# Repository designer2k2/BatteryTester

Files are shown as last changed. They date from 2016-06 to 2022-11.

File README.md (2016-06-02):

# BatteryTester
Arduino Shield to test 1-3S LiPo´s

There are KiCad Files (for 4.0.2) and the Arduino Programm here!

This shield has large resistors switched by mosfets, that gives the possibilty to change the load to the connected cells.

Image of Prototype

it measures the capacity and Internal resistance, you can plot the data in graphs if you like:

Image of discharge curve

It is based on my prototype from here: http://www.designer2k2.at/mods/arduino/70-battery-tester

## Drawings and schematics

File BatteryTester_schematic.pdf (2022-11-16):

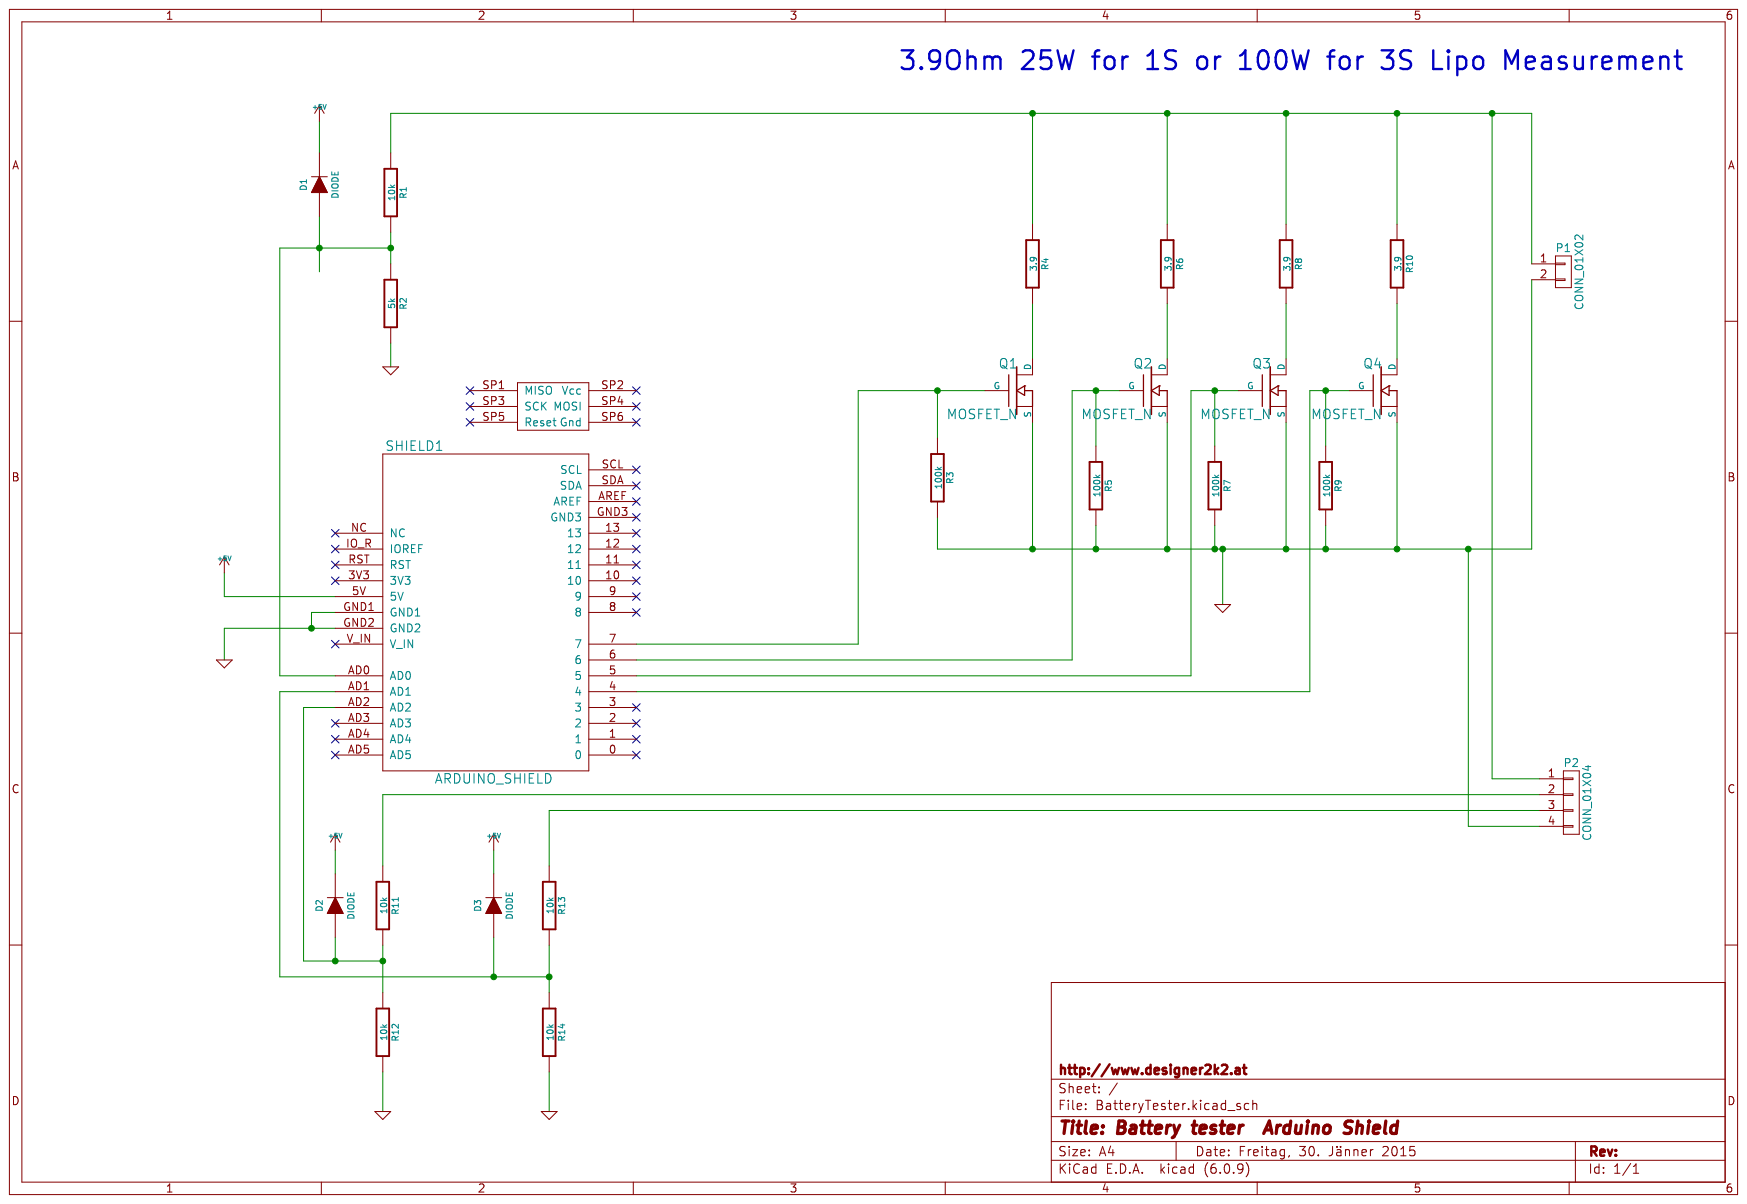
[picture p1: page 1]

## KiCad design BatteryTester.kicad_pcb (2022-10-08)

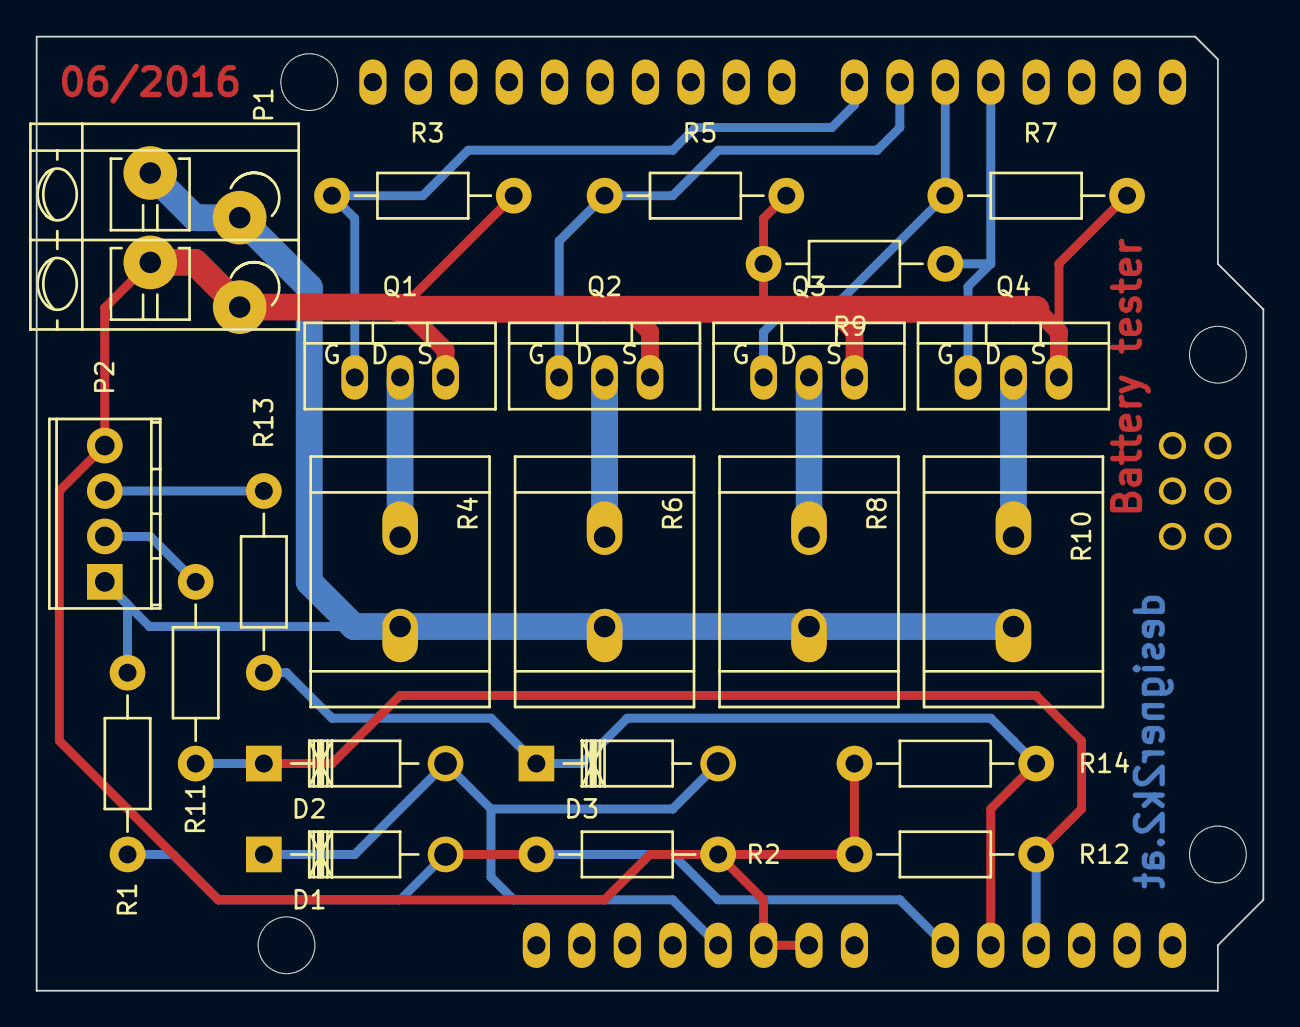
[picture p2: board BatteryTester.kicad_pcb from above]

Board: 2 copper layers, 68.6 x 53.3 mm, 24 parts (0 on the bottom side), 16 nets.

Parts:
D1, D2, D3: DIODE; Diode_DO-41_SOD81_Horizontal_RM10
P1: CONN_01X02; TerminalBlock_WAGO-804_RM5mm_2pol
P2: CONN_01X04; TerminalBlock_Pheonix_MPT-2.54mm_4pol
Q1, Q2, Q3, Q4: MOSFET_N; TO-220_FET-GDS_Vertical
R1, R11, R12, R13, R14: 10k; Resistor_Horizontal_RM10mm
R2: 5k; Resistor_Horizontal_RM10mm
R3, R5, R7, R9: 100k; Resistor_Horizontal_RM10mm
R4, R6, R8, R10: 3.9; Resistor_Cement_Vertical_LargePads_KOA-BGR-5N-7N
SHIELD1: ARDUINO_SHIELD

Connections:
+5V: D1.2, D2.2, D3.2, SHIELD1.5V
GND: P1.2, P2.4, Q1.S, Q2.S, Q3.S, Q4.S, R2.2, R3.2, R5.2, R7.2, R9.2, R12.2, R14.2, SHIELD1.GND1, SHIELD1.GND2
unnamed: D1.1, R1.2, R2.1, SHIELD1.AD0
unnamed: D2.1, R11.2, R12.1, SHIELD1.AD2
unnamed: D3.1, R13.2, R14.1, SHIELD1.AD1
unnamed: P1.1, P2.1, R1.1, R4.1, R6.1, R8.1, R10.1
unnamed: P2.2, R11.1
unnamed: P2.3, R13.1
unnamed: Q1.D, R4.2
unnamed: Q1.G, R3.1, SHIELD1.7
unnamed: Q2.D, R6.2
unnamed: Q2.G, R5.1, SHIELD1.6
unnamed: Q3.D, R8.2
unnamed: Q3.G, R7.1, SHIELD1.5
unnamed: Q4.D, R10.2
unnamed: Q4.G, R9.1, SHIELD1.4

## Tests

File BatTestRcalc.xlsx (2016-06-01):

Zellen: | 1
V: | 3.7
 |  | Ohm | A | W | AT | WT
 |  | 3.9 | 0.95 | 3.51 | 4.74 | 17.55
 |  | 3.9 | 0.95 | 3.51
 |  | 3.9 | 0.95 | 3.51
 |  | 1.95 | 1.90 | 7.02

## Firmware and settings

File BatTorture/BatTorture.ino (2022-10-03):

//Battery Tester by Stephan Martin
//http://www.designer2k2.at
// 03.07.2012 Initial Version
// 31.08.2012 Start to add Ri Measurement (1sec free, 1sec 1A, 1sec free, 1sec 2A, 1sec free, 1sec 3A, 1sec free) NO Protection
// 09.09.2014 Extend Ri Measurement (take last sample and calc Ri)
// 17.09.2014 Start to add Capacity measurement, per chanel we have a 3.9Ohms R
// 10.10.2014 Capacity works, now add Wh, and make Ri automatically, maybe use timer to get 100ms intervall?

#include<stdlib.h> //for dtostrf(FLOAT,WIDTH,PRECSISION,BUFFER);
static char dtostrfbuffer1[20];

const int analogInPin = 0;  // Analog input pin that the Battery is attached to

int sensorValue = 0;        // value read from the Battery
float SensorVoltage = 0.0;
int ChargeInput = 0;
unsigned long time;
unsigned long Start = 0;
int Mosfets = 0;
boolean RunIt = false;
boolean ChargeIt = false;

float FreeVoltage, Volt1A, Volt2A, Volt3A, Ri1A, Ri2A, Ri3A;

float fCapacity = 0.0;
unsigned long lasttime = 0;

void setup() {

  //Define Mosfet Pins as Outputs
  pinMode(5, OUTPUT);
  pinMode(6, OUTPUT);
  pinMode(7, OUTPUT);

  //And the Charge IC Pins:
  pinMode(4, OUTPUT); //Current select (High 500ma, Low 100ma)
  pinMode(2, OUTPUT); //Enable (High On, Low Off)

  //and give them a clear off:
  digitalWrite(5, LOW);
  digitalWrite(6, LOW);
  digitalWrite(7, LOW);
  digitalWrite(4, LOW);
  digitalWrite(2, LOW);

  // initialize serial communications at 9600 bps:
  Serial.begin(57600);

  pinMode(13, OUTPUT);

  // Ask for the Mosfets
  IntroTextSend();

}

void loop() {



  // check if data has been sent from the computer:
  if (Serial.available()) {
    Mosfets = Serial.parseInt();
    //Serial.print(Mosfets);

    switch (Mosfets) {
      case 1:
        //1 Mosfet (Center)
        Serial.println("Activate the center, 1A!");
        digitalWrite(2, LOW);
        digitalWrite(4, LOW);
        ChargeIt = false;
        digitalWrite(5, LOW);
        digitalWrite(6, HIGH);
        digitalWrite(7, LOW);
        RunIt = true;
        break;
      case 2:
        //2 Mosfet (edges)
        Serial.println("Activate the edges, 2A!");
        digitalWrite(2, LOW);
        digitalWrite(4, LOW);
        ChargeIt = false;
        digitalWrite(5, HIGH);
        digitalWrite(6, LOW);
        digitalWrite(7, HIGH);
        RunIt = true;
        break;
      case 3:
        //3 Mosfet (all)
        Serial.println("Activate ALL, 3A!");
        digitalWrite(2, LOW);
        digitalWrite(4, LOW);
        ChargeIt = false;
        digitalWrite(5, HIGH);
        digitalWrite(6, HIGH);
        digitalWrite(7, HIGH);
        RunIt = true;
        break;
      case 4:
        //Charge with 100mA
        Serial.println("Charge with 100mA");
        digitalWrite(5, LOW);
        digitalWrite(6, LOW);
        digitalWrite(7, LOW);
        digitalWrite(2, HIGH);
        digitalWrite(4, LOW);
        RunIt = false;
        ChargeIt = true;
        fCapacity = 0.0;
        break;
      case 5:
        //Charge with 500mA
        Serial.println("Charge with 500mA");
        digitalWrite(5, LOW);
        digitalWrite(6, LOW);
        digitalWrite(7, LOW);
        digitalWrite(2, HIGH);
        digitalWrite(4, HIGH);
        RunIt = false;
        ChargeIt = true;
        fCapacity = 0.0;
        break;
      case 6:
        //Just print current Voltage
        // read the analog in value:
        sensorValue = analogRead(analogInPin);
        SensorVoltage = sensorValue * (5.0 / 1023.0);
        Serial.print("Current Voltage: ");
        Serial.println(SensorVoltage);
        break;
      case 7:
        //Hardcoded Ri Measurement
        Serial.println("Starting Ri Measurement, no Undervolt Protection!");
        Serial.println("Best to use 50% Charged LiPos (3,8V)");
        delay(2000);
        RunIt = false;
        ChargeIt = false;
        fCapacity = 0.0;
        RiMeasurement();
        break;
      default:
        Serial.println("");
        Serial.print("NO Idea what: ");
        Serial.print(Mosfets);
        Serial.println(" should be.");
        // read the analog in value:
        sensorValue = analogRead(analogInPin);
        SensorVoltage = sensorValue * (5.0 / 1023.0);
        Serial.print("Current Voltage: ");
        Serial.println(SensorVoltage);
        RunIt = false;
        ChargeIt = false;
        digitalWrite(5, LOW);
        digitalWrite(6, LOW);
        digitalWrite(7, LOW);
        digitalWrite(4, LOW);
        digitalWrite(2, LOW);
        fCapacity = 0.0;
        IntroTextSend();

    }

    Start = millis();
    lasttime = Start;
  }


  // read the analog in value:
  sensorValue = analogRead(analogInPin);
  SensorVoltage = sensorValue * (5.0 / 1023.0);

  ChargeInput = ChargeInput * 0.5 + analogRead(1) * 0.5 ; //Reads the CHG Input from the Charger IC

  //if the Voltage is below 3.2V Turn on the LED, and OFF Them Mosfets!
  if (SensorVoltage < 3.2) {
    digitalWrite(13, HIGH);
    digitalWrite(5, LOW);
    digitalWrite(6, LOW);
    digitalWrite(7, LOW);
    if (RunIt == true) {
      Serial.println("Shutoff!!!!! UNDERVOLTAGE!!!!");
      RunIt = false;
      fCapacity = 0.0;
      IntroTextSend();
    }
  } else
  {
    digitalWrite(13, LOW);
  }

  //fetch the time:
  time = millis();

  // print the results to the serial monitor (only if needed)
  if (RunIt == true) {
    PrintLogLine(Mosfets);
  }

  // Watches over the Charging Process:

  if (ChargeIt == true) {

    if (ChargeInput <= 400) {
      Serial.print(time - Start);
      Serial.print(";");
      Serial.print(SensorVoltage);
      Serial.print(";");
      Serial.println(ChargeInput);
    } else
    {
      //Charge Finished
      ChargeIt = false;
      digitalWrite(4, LOW);
      digitalWrite(2, LOW);
      Serial.println("Shutoff!!!!! LiPo Full!!!");
      IntroTextSend();
    }

  }

  // wait 100 milliseconds before the next loop
  delay(98);
  delayMicroseconds(600);
}


//---------------------------------------------------------------------------------

void RiMeasurement() {

  int iTimepassed;

  Start = millis();

  //1Sec Free
  digitalWrite(5, LOW);
  digitalWrite(6, LOW);
  digitalWrite(7, LOW);
  digitalWrite(13, HIGH);

  do {
    PrintLogLine(0);
    delay(10);
    iTimepassed = time - Start;
  } while (iTimepassed <= 100);

  FreeVoltage = SensorVoltage;

  //1Sec 1A
  digitalWrite(5, LOW);
  digitalWrite(6, HIGH);
  digitalWrite(7, LOW);
  digitalWrite(13, LOW);

  do {
    PrintLogLine(1);
    delay(10);
    iTimepassed = time - Start;
  } while (iTimepassed <= 200);

  Volt1A = SensorVoltage;
  Ri1A = (FreeVoltage - Volt1A) / 1.0;

  //1Sec Free
  digitalWrite(5, LOW);
  digitalWrite(6, LOW);
  digitalWrite(7, LOW);
  digitalWrite(13, HIGH);

  do {
    PrintLogLine(0);
    delay(10);
    iTimepassed = time - Start;
  } while (iTimepassed <= 300);

  FreeVoltage = SensorVoltage;

  //1Sec 2A
  digitalWrite(5, HIGH);
  digitalWrite(6, LOW);
  digitalWrite(7, HIGH);
  digitalWrite(13, LOW);

  do {
    PrintLogLine(2);
    delay(10);
    iTimepassed = time - Start;
  } while (iTimepassed <= 400);

  Volt2A = SensorVoltage;
  Ri2A = (FreeVoltage - Volt2A) / 2.0;

  //1Sec Free
  digitalWrite(5, LOW);
  digitalWrite(6, LOW);
  digitalWrite(7, LOW);
  digitalWrite(13, HIGH);

  do {
    PrintLogLine(0);
    delay(10);
    iTimepassed = time - Start;
  } while (iTimepassed <= 500);

  FreeVoltage = SensorVoltage;

  //1Sec 3A
  digitalWrite(5, HIGH);
  digitalWrite(6, HIGH);
  digitalWrite(7, HIGH);
  digitalWrite(13, LOW);

  do {
    PrintLogLine(3);
    delay(10);
    iTimepassed = time - Start;
  } while (iTimepassed <= 600);

  Volt3A = SensorVoltage;
  Ri3A = (FreeVoltage - Volt3A) / 3.0;

  //1Sec Free

  digitalWrite(5, LOW);
  digitalWrite(6, LOW);
  digitalWrite(7, LOW);
  digitalWrite(13, HIGH);

  do {
    PrintLogLine(0);
    delay(10);
    iTimepassed = time - Start;
  } while (iTimepassed <= 700);

  FreeVoltage = SensorVoltage;

  Serial.println("Ri Measurement done. Result:");

  Serial.print("Ri 1A: ");
  Serial.print(Ri1A * 1000.0);
  Serial.print("mOhm Ri 2A: ");
  Serial.print(Ri2A * 1000.0);
  Serial.print("mOhm Ri 3A: ");
  Serial.print(Ri3A * 1000.0);
  Serial.println("mOhm");

}

void IntroTextSend() {
  Serial.println("What to do??");
  Serial.println("Enter 1-3 to Discharge wit 1-3A");
  Serial.println("Enter 4-5 to charge with 100/500mA");
  Serial.println("Enter 6 to show current voltage");
  Serial.println("Enter 7 to make a Ri Cycle");

}

void PrintLogLine(int iC) {

  unsigned long deltatime;
  float deltacap;

  //fetch the time:
  time = millis();

  // read the analog in value:
  sensorValue = analogRead(analogInPin);
  SensorVoltage = sensorValue * (5.0 / 1023.0);

  // make the capacity measurement:
  deltatime = time - lasttime;
  deltacap = (SensorVoltage / (3.9 / iC)) * deltatime; //This should be Ams
  fCapacity = fCapacity + deltacap;

  float fCap2;
  fCap2 = fCapacity / 3600.0; // from Ams to mAh

  String sCapacity;
  dtostrf(fCap2, 6, 2, dtostrfbuffer1);
  sCapacity = dtostrfbuffer1;
  sCapacity.replace(".", ",");
  sCapacity.replace(" ", "");

  String sSensorVoltage;
  dtostrf(SensorVoltage, 6, 2, dtostrfbuffer1);
  sSensorVoltage = dtostrfbuffer1;
  sSensorVoltage.replace(".", ",");
  sSensorVoltage.replace(" ", "");


  Serial.print(time - Start);
  Serial.print(";");
  Serial.print(sSensorVoltage);
  Serial.print(";");
  Serial.print(sCapacity);
  Serial.print(";");
  Serial.println(iC);

  lasttime = time;

}

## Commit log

2016-06-01 Initial Fill
    KiCad 4.0.2 Files incl. Gerber´s that qualify for OSHpark
    [BatTestRcalc.xlsx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]
2016-06-01 Initial Fill
    Arduino Sourcecode (testet on Prototype, not on the PCB!)
2022-10-03 Arduino formatting
    [STRG]+[T] formatting
2022-10-04 Update to KiCad 6
    [BatteryTester.kicad_pcb, BatteryTester.kicad_sch, BatteryTester.sch]
2022-10-04 Add bom list
2022-10-08 Update Gerbers
    [BatteryTester-B.Cu.gbl, BatteryTester-B.Mask.gbs, BatteryTester-B.Paste.gbp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]
2022-11-16 Create BatteryTester_schematic.pdf
    Add schematic
